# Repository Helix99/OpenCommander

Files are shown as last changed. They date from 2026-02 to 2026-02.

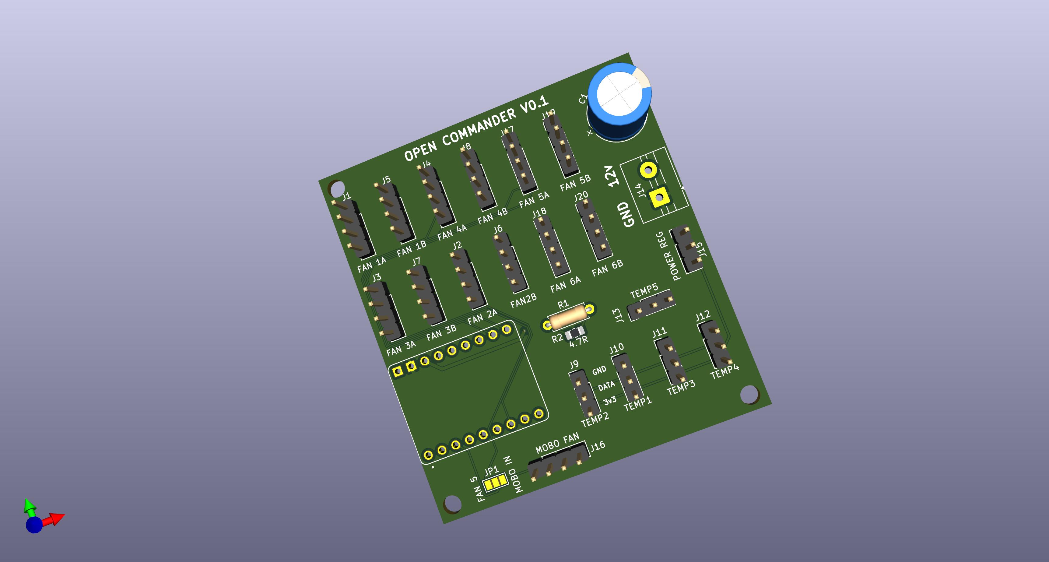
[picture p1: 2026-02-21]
esp32_fan_controller_v0.1.jpg

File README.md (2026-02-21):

# OpenCommander
USB Fan and temprature sensor managment firmware, application and board.

I have a linux server but the supermicro motherboard has limited fan headders and thermal zones. I wanted a much more flexible thermal management solution for it. 

Can manage 6 groups of 2 fans (12 total)
Up to 5 x DS18B20 temprature sensors
Posibillity to disable fan 5 and use pin as input from motherboard fan headder (yet to be implimented in firmware)

Emulates the corsair commander pro firmware so that the fans and tempratures show up in Linux using the in tree corsair module.

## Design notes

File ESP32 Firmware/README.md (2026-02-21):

# ESP32-S3 SuperMini Fan Controller

A complete 4-channel PWM fan controller with 5× DS18B20 temperature monitoring, emulating a **Corsair Commander Pro** over USB HID. Works natively with Linux `lm-sensors`, `fancontrol`, and Prometheus/Grafana — zero custom drivers.

---

## Features

- 6× 4-pin PWM fans (25 kHz, 8-bit, 0–100%)
- 5× DS18B20 temperature sensors (1-Wire, 12-bit, 0.0625 °C resolution)
- Independent fan curves with hysteresis per fan
- Safety override: all fans → 100% if any sensor exceeds 85 °C
- Smooth PWM ramping (prevents bearing stress)
- Friendly sensor names stored in NVS across reboots
- Composite USB: CDC serial + HID simultaneously on one USB-C cable
- Corsair Commander Pro HID protocol (VID `0x1b1c` / PID `0x0c10`)
- Automatic `corsair-cpro` kernel driver load on Linux ≥ 5.8
- JSON serial protocol for Python CLI / scripting

---

## Hardware

### Bill of Materials

| Component | Qty | UK/EU Source | US Source |
|---|---|---|---|
| ESP32-S3 SuperMini | 1 | AliExpress ~£3 | Amazon/AliExpress ~$4 |
| DS18B20 (TO-92) | 5 | Farnell, AliExpress | Mouser, DigiKey |
| 4.7 kΩ resistor | 1 | Any | Any |
| 1 kΩ resistor | 4 | Any | Any |
| 100 nF ceramic cap | 4 | Any | Any |
| 10 µF electrolytic cap | 2 | Any | Any |
| 4-pin PWM fan header (PCB) | 4 | AliExpress | Amazon |
| 12 V PSU (≥5 A for 4× 120 mm fans) | 1 | Amazon ~£12 | Amazon ~$15 |
| Screw terminals / prototype PCB | 1 set | AliExpress | Amazon |

### Pin Assignments

| Function | GPIO | Notes |
|---|---|---|
| PWM Fan 1–4 | 1, 2, 3, 4 | LEDC output, 3.3 V logic OK |
| Tachometer Fan 1–4 | 5, 6, 7, 8 | INPUT_PULLUP, FALLING edge ISR |
| 1-Wire (DS18B20) | 9 | External 4.7 kΩ pull-up to 3.3 V |
| Status LED | 48 | Built-in on SuperMini |
| USB D−/D+ | 19/20 | **Reserved — do not use** |
| Strapping | 0, 45, 46 | **Avoid for peripherals** |

### Wiring Diagram

```
                  ESP32-S3 SuperMini
                 ┌──────────────────┐
            3.3V │                  │ GPIO1 ──PWM──► Fan1 Pin4
             GND │                  │ GPIO2 ──PWM──► Fan2 Pin4
                 │                  │ GPIO3 ──PWM──► Fan3 Pin4
                 │                  │ GPIO4 ──PWM──► Fan4 Pin4
                 │                  │
                 │                  │ GPIO5 ◄─TACH── Fan1 Pin3
                 │                  │ GPIO6 ◄─TACH── Fan2 Pin3
                 │                  │ GPIO7 ◄─TACH── Fan3 Pin3
                 │                  │ GPIO8 ◄─TACH── Fan4 Pin3
                 │                  │
                 │                  │ GPIO9 ◄──┬──► DS18B20 ×5 (DQ)
                 │             3.3V ├──────────┤ 4.7 kΩ pull-up
                 │                  │
                 │  USB-C (19/20)   │◄──────────────── USB to Linux host
                 └──────────────────┘

Fan 4-pin connector:
  Pin1 GND  ──── Common ground
  Pin2 12V  ──── 12 V PSU
  Pin3 TACH ──── 1 kΩ ──── GPIO (internal pull-up active)
  Pin4 PWM  ──── GPIO output

DS18B20 (×5, all in parallel):
  VDD ──── 3.3 V
  GND ──── GND
  DQ  ──┬─ GPIO 9
        └─ 4.7 kΩ ──── 3.3 V

Power rail (CRITICAL — shared ground):
  12 V PSU(+) ──── Fan Pin2 (×4)
  12 V PSU(−) ──┬─ Fan Pin1 (×4)
                └─ ESP32-S3 GND
```

---

## PlatformIO Setup

### Install

```bash
pip install platformio
# Or use VS Code with the PlatformIO extension
```

### Flash (first time — BOOT mode entry)

1. Hold **BOOT** button on the SuperMini
2. Press and release **RESET** while holding BOOT
3. Release **BOOT** — device enters download mode
4. Run:

```bash
cd esp32s3-fan-controller
pio run --target upload
```

After the first flash, subsequent uploads work automatically over CDC serial if ARDUINO_USB_CDC_ON_BOOT is handled correctly, or repeat the BOOT+RESET sequence.

### Monitor

```bash
pio device monitor -b 115200 -p /dev/ttyACM0
```

---

## First-Run Guide

### 1. Flash firmware

Follow the BOOT mode entry steps above.

### 2. Open serial terminal

```bash
screen /dev/ttyACM0 115200
# or: pio device monitor
```

### 3. Discover sensors

```
LIST_SENSORS
{"sensors":[{"index":0,"rom":"28FF3A2B0C000042","name":"Sensor 1"},…]}
```

### 4. Assign friendly names

```
SET_NAME 28FF3A2B0C000042 CPU Temperature
SET_NAME 28FF... GPU Temperature
```

### 5. Verify temperatures

```
GET_TEMPS
{"temps":[{"name":"CPU Temperature","rom":"28FF3A2B0C000042","value":42.5,"valid":true},…]}
```

### 6. Set fan curves

```
SET_CURVE 1 [[20,30],[40,50],[60,75],[80,100]]
SET_CURVE 2 [[20,30],[40,50],[60,75],[80,100]]
```

### 7. Map sensors to fans

```
SET_MAPPING 1 0   # Fan 1 follows sensor 0
SET_MAPPING 2 1   # Fan 2 follows sensor 1
```

### 8. Enable Corsair HID (device will reboot)

```
HID_ENABLE
```

### 9. Verify Linux detection

```bash
sensors
# Should show corsaircpro-hid-* with temperatures and RPMs
```

---

## Serial Protocol Reference

All commands are plain text. All responses are JSON terminated with `\n`.

| Command | Arguments | Response |
|---|---|---|
| `GET_TEMPS` | — | `{"temps":[{"name":"CPU","rom":"28FF…","value":45.5,"valid":true},…]}` |
| `GET_RPMS` | — | `{"rpms":[1200,1350,980,1100]}` |
| `SET_FAN` | `<fan 1–4> <pct 0–100>` | `{"ok":true}` |
| `SET_AUTO` | `<fan 1–4>` | `{"ok":true}` |
| `SET_ALL_AUTO` | — | `{"ok":true}` |
| `GET_CURVE` | `<fan 1–4>` | `{"fan":1,"curve":[[20,30],[40,50],…]}` |
| `SET_CURVE` | `<fan> [[t,p],…]` | `{"ok":true}` |
| `GET_MAPPING` | — | `{"mapping":[0,0,1,1]}` |
| `SET_MAPPING` | `<fan 1–4> <sensor 0–4>` | `{"ok":true}` |
| `LIST_SENSORS` | — | `{"sensors":[{"index":0,"rom":"28FF…","name":"CPU"},…]}` |
| `SET_NAME` | `<rom_hex> <name>` | `{"ok":true}` |
| `GET_STATUS` | — | Full system status JSON |
| `HID_ENABLE` | — | Reboots with HID active |
| `HID_DISABLE` | — | Reboots without HID |
| `SAVE_CONFIG` | — | `{"ok":true}` (no-op, saved on change) |
| `FACTORY_RESET` | — | Clears NVS, reboots |
| `VERSION` | — | `{"fw":"1.0.0","board":"ESP32-S3-SuperMini"}` |

---

## Corsair Commander Pro Protocol

HID reports: 16 bytes IN (device→host) and 16 bytes OUT (host→device).

| Cmd byte | Function | Request | Response |
|---|---|---|---|
| `0x01` | Firmware version | `[0x01, 0x00, …]` | `[0x01, 0x00, 0x09, 0x45]` |
| `0x02` | Product name | `[0x02, …]` | `[0x02, "Commander Pro"…]` |
| `0x08` | Sensor count | `[0x08, …]` | `[0x08, 0x05]` |
| `0x09` | Fan count | `[0x09, …]` | `[0x09, 0x04]` |
| `0x10` | Get temperature | `[0x10, sensor_idx, …]` | `[0x10, hi, lo]` (hundredths °C) |
| `0x21` | Get fan RPM | `[0x21, fan_idx, …]` | `[0x21, hi, lo]` |
| `0x23` | Set fan PWM % | `[0x23, fan_idx, pct, …]` | `[0x23, 0x00]` |
| `0x60` | Set fan mode | `[0x60, fan_idx, mode, …]` | `[0x60, 0x00]` (0=manual, 1=auto) |

---

## Fan Curve Profiles

### Silent
`[[20,20],[35,25],[50,40],[65,60],[75,85],[85,100]]`

### Balanced (default)
`[[20,30],[40,50],[60,75],[80,100]]`

### Performance
`[[20,50],[35,65],[50,80],[60,100]]`

---

## Linux Integration

### Automatic with corsair-cpro kernel module (Linux ≥ 5.8)

```bash
# Plug in with HID enabled — driver loads automatically
cat /sys/class/hwmon/hwmon*/name | grep corsair
# corsaircpro

sensors
# Shows temps and fan RPMs
```

### Sensor labels — /etc/sensors.d/fan-controller.conf

```conf
chip "corsaircpro-*"
    label temp1 "CPU Temperature"
    label temp2 "GPU Temperature"
    label temp3 "Motherboard"
    label temp4 "Intake Air"
    label temp5 "Exhaust Air"
    label fan1  "CPU Fan"
    label fan2  "GPU Fan"
    label fan3  "Front Intake"
    label fan4  "Rear Exhaust"
```

### fancontrol

```bash
sudo pwmconfig   # Auto-generates /etc/fancontrol
sudo systemctl enable --now fancontrol
```

### Prometheus (node_exporter)

```bash
node_exporter --collector.hwmon
# node_hwmon_temp_celsius{chip="corsaircpro",sensor="temp1"} 45.5
# node_hwmon_fan_rpm{chip="corsaircpro",sensor="fan1"} 1200
```

---

## Troubleshooting

### SuperMini not detected / upload fails
- Enter BOOT mode: hold BOOT, press RESET, release BOOT
- Check USB cable supports data (not charge-only)
- Try `lsusb` to confirm device appears

### HID not enumerating
- Verify `USB_VID=0x1b1c`, `USB_PID=0x0c10` build flags are present
- Check `ARDUINO_USB_MODE=0` is set (native USB, not UART bridge)
- Inspect `lsusb -v` output

### corsair-cpro module not loading
```bash
uname -r        # Kernel must be ≥ 5.8
modprobe corsair-cpro
dmesg | tail    # Check for binding errors
```

### DS18B20 not found (GET_TEMPS returns empty)
- Confirm 4.7 kΩ pull-up is on DQ line to 3.3 V
- Confirm sensors are NOT in parasite mode (VDD tied to 3.3 V, not left floating)
- Try with a single sensor first
- Check GPIO 9 is free (no other peripheral assigned)

### Fan tachometer reads 0 RPM
- Confirm `IRAM_ATTR` on ISR functions (already present in source)
- Check 1 kΩ series resistor and internal pull-up on GPIO 5–8
- Verify fan Pin 3 tach wire is connected
- Some fans emit 1 pulse/rev — adjust `TACH_PULSES_PER_REV` in `shared_types.h`

### CDC serial and HID not both present
- Confirm composite USB setup: `hidHandler_init()` called before `USB.begin()`
- Check `ARDUINO_USB_CDC_ON_BOOT=0` — CDC must be managed manually (done in `main.cpp`)
- If only one interface appears, try a powered USB hub (some ports limit current during enumeration)

---

## Code Structure

```
esp32s3-fan-controller/
├── platformio.ini           Board, framework, build flags, lib deps
├── include/
│   └── shared_types.h       All structs, enums, pin/constant defines
└── src/
    ├── main.cpp             Setup, USB init, FreeRTOS task creation, heartbeat
    ├── config_store.cpp/h   Preferences NVS wrapper (curves, mapping, names, HID flag)
    ├── fan_control.cpp/h    LEDC PWM init, duty write, ramping
    ├── tachometer.cpp/h     ISR pulse counting, RPM calculation, stall detection
    ├── temperature.cpp/h    OneWire/DallasTemperature async read, ROM→hex helpers
    ├── fan_curve.cpp/h      Breakpoint interpolation, hysteresis, safety override
    ├── hid_handler.cpp/h    USBHIDGeneric subclass, Commander Pro protocol
    └── serial_handler.cpp/h CDC command parser, JSON responses (ArduinoJson)
```

### FreeRTOS Tasks

| Task | Core | Period | Responsibility |
|---|---|---|---|
| `HID` | 0 | 2000 ms | Push Commander Pro HID report, process host commands |
| `Serial` | 0 | Event | Parse CDC serial commands, return JSON |
| `Temp` | 1 | 2000 ms | Async DS18B20 conversion + read |
| `Control` | 1 | 50 ms | Apply fan curves, ramp PWM |
| `Tacho` | 1 | 2000 ms | Calculate RPM from ISR counters |

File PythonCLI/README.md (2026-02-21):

# ESP32-S3 Fan Controller CLI

Companion Python app for the ESP32-S3 SuperMini fan controller firmware
with Corsair Commander Pro emulation.

---

## Requirements

Python 3.10+ (uses `X | Y` type hints and `match`)

```bash
pip install -r requirements.txt
```

---

## Quick Start

```bash
# Auto-detect the device port
python fan_controller_cli.py

# Specify port explicitly
python fan_controller_cli.py --port /dev/ttyACM0

# Windows
python fan_controller_cli.py --port COM5

# Jump straight to live dashboard
python fan_controller_cli.py --dashboard
```

The last-used port is saved to `~/.fan_controller_config.json` so you won't
need to select it again on subsequent runs.

---

## Features

| Feature | Description |
|---|---|
| **Auto port detection** | Scans for CDC ACM / Corsair VID devices automatically |
| **Live dashboard** | Refreshes every 2 s — all temperatures + fan RPMs with colour coding |
| **Manual fan control** | Set any fan to a fixed PWM % or return to auto/curve mode |
| **Fan curve editor** | Built-in presets (Silent / Balanced / Performance) + custom entry |
| **Sensor naming wizard** | Lists discovered DS18B20 ROM addresses and prompts for friendly names |
| **Sensor mapping** | Choose which temperature sensor controls each fan |
| **HID toggle** | Enable/disable Corsair Commander Pro USB HID emulation (triggers reboot) |
| **Export** | Save current readings to JSON or CSV with timestamp |
| **Device status** | Firmware version, board ID, uptime, HID state |
| **Factory reset** | Double-confirmed wipe of all NVS config |

---

## Live Dashboard

Colour coding:

| Colour | Meaning |
|---|---|
| Green | Normal (temp < 50 °C / fan spinning) |
| Yellow | Warm (temp 50–70 °C) |
| Orange | Hot (temp 70–80 °C) |
| Red | Critical (temp ≥ 80 °C) or fan stalled (0 RPM) |

---

## Fan Curve Presets

| Profile | Breakpoints |
|---|---|
| Silent | 20→20%, 35→25%, 50→40%, 65→60%, 75→85%, 85→100% |
| Balanced | 20→30%, 40→50%, 60→75%, 80→100% |
| Performance | 20→50%, 35→65%, 50→80%, 60→100% |

You can also enter custom breakpoints with up to 8 points. Temperatures must
be strictly ascending.

---

## Linux `sensors` Integration

After enabling HID emulation and rebooting the device:

```bash
# Verify the kernel driver loaded
$ lsmod | grep corsair
corsair_cpro           ...

# Check hwmon
$ sensors
corsaircpro-hid-3-3
Adapter: HID adapter
CPU Temperature:  +45.5°C
GPU Temperature:  +52.2°C
fan1:            1200 RPM
fan2:            1350 RPM
fan3:             980 RPM
fan4:            1100 RPM
```

Add sensor labels in `/etc/sensors.d/fan-controller.conf`:

```conf
chip "corsaircpro-*"
    label temp1 "CPU Temperature"
    label temp2 "GPU Temperature"
    label temp3 "Motherboard"
    label fan1  "CPU Fan"
    label fan2  "GPU Fan"
```

---

## Troubleshooting

**Device not detected**
- Check the ESP32-S3 is powered and the USB-C cable supports data
- Try entering download mode: hold BOOT, press RESET, release BOOT
- On Linux check `dmesg | grep ttyACM` after plugging in
- Add yourself to the `dialout` group: `sudo usermod -aG dialout $USER` (re-login required)

**Timeout errors**
- The firmware may still be booting — wait ~3 s and retry
- Check baud rate matches firmware (default 115200)
- Try unplugging and replugging the USB cable

**HID not loading `corsair-cpro`**
- Requires kernel 5.8+: `uname -r`
- Try: `sudo modprobe corsair-cpro`
- Verify VID/PID: `lsusb | grep -i corsair` should show `1b1c:0c10`

**Fan RPM reading 0**
- Check tachometer wiring (Fan Pin 3) and pull-up
- ISR functions must be marked `IRAM_ATTR` in firmware
- Some fans don't emit tach pulses below ~20% PWM — raise minimum speed

**DS18B20 shows -127 °C**
- Sensor disconnected or wiring fault
- Check 4.7 kΩ pull-up resistor on the data line
- Ensure NOT using parasite mode (VDD connected to 3.3 V, not data line)

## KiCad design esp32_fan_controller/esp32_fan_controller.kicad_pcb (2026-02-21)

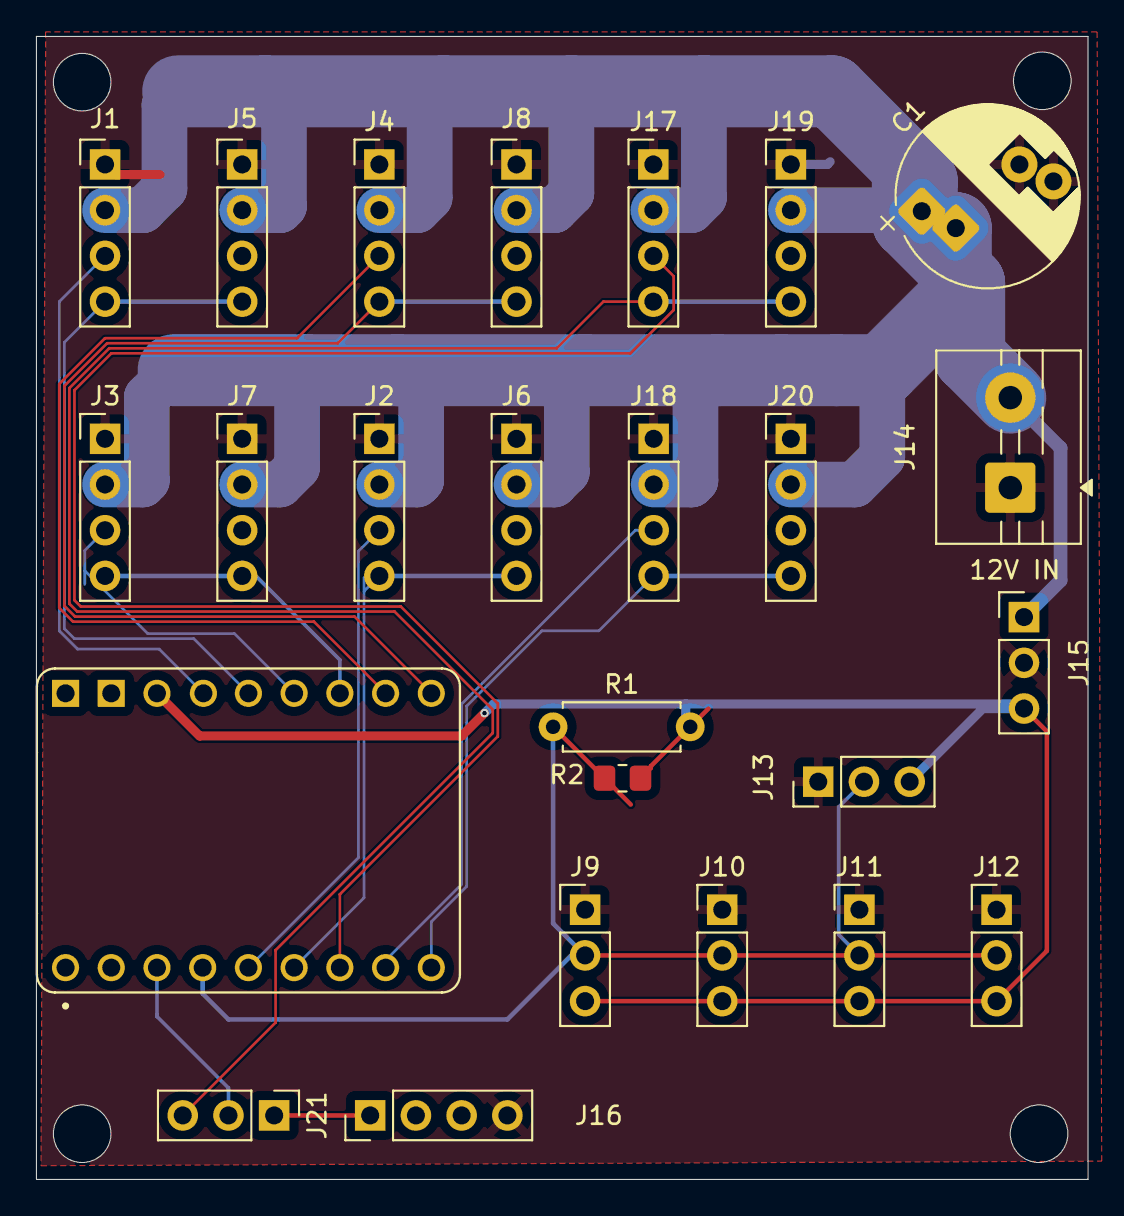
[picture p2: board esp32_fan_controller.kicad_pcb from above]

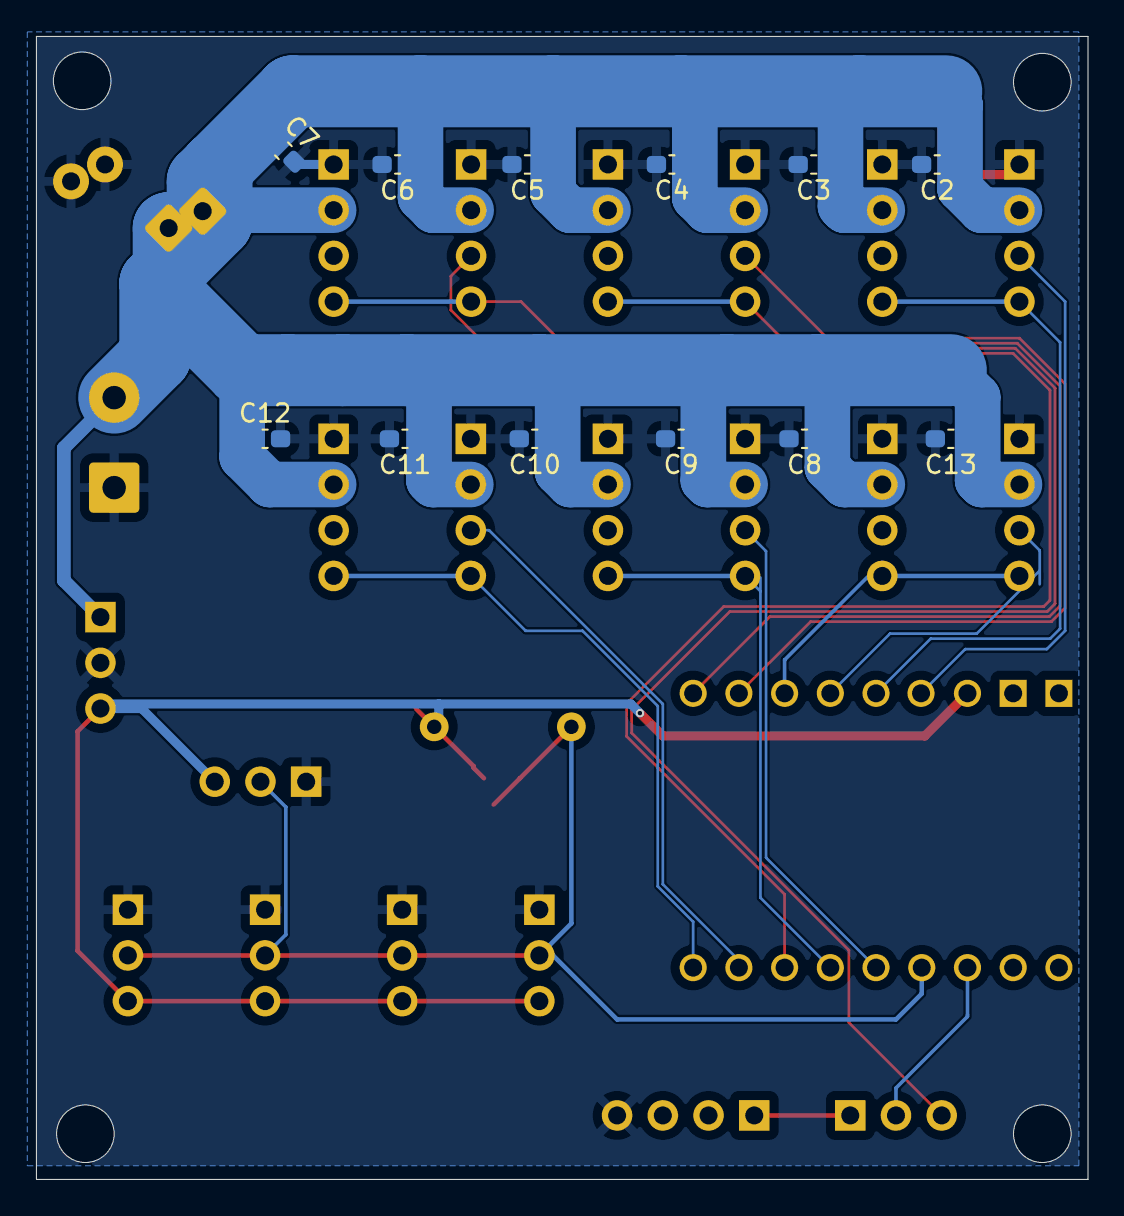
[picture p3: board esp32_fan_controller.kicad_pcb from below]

Board: 2 copper layers, 58.4 x 63.5 mm, 37 parts (12 on the bottom side), 18 nets.

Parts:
C1: C_Polarized; CP_Radial_D10.0mm_P5.00mm_P7.50mm
C2, C3, C4, C5, C6, C7, C8, C9, C10, C11, C12, C13: C; C_0603_1608Metric_Pad1.08x0.95mm_HandSolder
J1: FAN 1A; PinHeader_1x04_P2.54mm_Vertical
J2: FAN 2A; PinHeader_1x04_P2.54mm_Vertical
J3: FAN 3A; PinHeader_1x04_P2.54mm_Vertical
J4: FAN 4A; PinHeader_1x04_P2.54mm_Vertical
J5: FAN 1B; PinHeader_1x04_P2.54mm_Vertical
J6: FAN2B; PinHeader_1x04_P2.54mm_Vertical
J7: FAN 3B; PinHeader_1x04_P2.54mm_Vertical
J8: FAN 4B; PinHeader_1x04_P2.54mm_Vertical
J9: TEMP2; PinHeader_1x03_P2.54mm_Vertical
J10: TEMP1; PinHeader_1x03_P2.54mm_Vertical
J11: TEMP3; PinHeader_1x03_P2.54mm_Vertical
J12: TEMP4; PinHeader_1x03_P2.54mm_Vertical
J13: TEMP5; PinHeader_1x03_P2.54mm_Vertical
J14: 12V IN; TerminalBlock_MaiXu_MX126-5.0-02P_1x02_P5.00mm
J15: POWER REG; PinHeader_1x03_P2.54mm_Vertical
J16: MOBO FAN; PinHeader_1x04_P2.54mm_Vertical
J17: FAN 5A; PinHeader_1x04_P2.54mm_Vertical
J18: FAN 6A; PinHeader_1x04_P2.54mm_Vertical
J19: FAN 5B; PinHeader_1x04_P2.54mm_Vertical
J20: FAN 6B; PinHeader_1x04_P2.54mm_Vertical
J21: GPIO1; PinHeader_1x03_P2.54mm_Vertical
R1: R; R_Axial_DIN0207_L6.3mm_D2.5mm_P7.62mm_Horizontal
R2: 4.7R; R_0805_2012Metric_Pad1.20x1.40mm_HandSolder
U1: ESP32-S3 SuperMini; ESP32-S3-SuperMini

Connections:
+3.3V: J9.3, J10.3, J11.3, J12.3, J13.3, J15.3, R1.2, R2.2
+12V: C1.1, C2.1, C3.1, C4.1, C5.1, C6.1, C7.1, C8.1, C9.1, C10.1, C11.1, C12.1, C13.1, J1.2, J2.2, J3.2, J4.2, J5.2, J6.2, J7.2, J8.2, J14.2, J15.1, J17.2, J18.2, J19.2, J20.2
GND: C1.2, C2.2, C3.2, C4.2, C5.2, C6.2, C7.2, C8.2, C9.2, C10.2, C11.2, C12.2, C13.2, J1.1, J2.1, J3.1, J4.1, J5.1, J6.1, J7.1, J8.1, J9.1, J10.1, J11.1, J12.1, J13.1, J14.1, J15.2, J16.4, J17.1, J18.1, J19.1, J20.1
unnamed: J1.3, U1.13 (GPIO13)
unnamed: J1.4, J5.4, U1.12 (GPIO12)
unnamed: J2.3, U1.3 (GPIO3)
unnamed: J2.4, J6.4, U1.4 (GPIO4)
unnamed: J3.3, U1.11 (GPIO11)
unnamed: J3.4, J7.4, U1.10 (GPIO10)
unnamed: J4.3, U1.9 (GPIO9)
unnamed: J4.4, J8.4, U1.8 (GPIO8)
unnamed: J9.2, J10.2, J11.2, J12.2, J13.2, R1.1, R2.1, U1.2 (GPI02)
unnamed: J16.1, J21.1
unnamed: J17.3, U1.5 (GPIO5)
unnamed: J17.4, J19.4, J21.3
unnamed: J18.3, U1.6 (GPIO6)
unnamed: J18.4, J20.4, U1.7 (GPIO7)
unnamed: J21.2, U1.1 (GPIO1)

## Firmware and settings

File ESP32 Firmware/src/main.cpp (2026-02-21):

/*
 * ESP32-S3 SuperMini Fan Controller
 * Corsair Commander Pro Emulation + CDC Serial Control
 *
 * Core 0: USB HID task, Serial handler task
 * Core 1: Temperature task, Fan control task, Tachometer task
 *
 * All shared state in g_state, protected by g_stateMutex.
 */

#include <Arduino.h>
#include <USB.h>
#include <USBCDC.h>
#include <freertos/FreeRTOS.h>
#include <freertos/task.h>
#include <freertos/semphr.h>

#include "shared_types.h"
#include "config_store.h"
#include "fan_control.h"
#include "tachometer.h"
#include "temperature.h"
#include "fan_curve.h"
#include "hid_handler.h"
#include "serial_handler.h"

// ─── Global State ────────────────────────────────────────────────────────────

SystemState         g_state;
SemaphoreHandle_t   g_stateMutex;
USBCDC              USBSerial;

// ─── Task Handles ────────────────────────────────────────────────────────────

TaskHandle_t taskHID     = nullptr;
TaskHandle_t taskSerial  = nullptr;
TaskHandle_t taskTemp    = nullptr;
TaskHandle_t taskControl = nullptr;
TaskHandle_t taskTacho   = nullptr;

// ─────────────────────────────────────────────────────────────────────────────
// Core 0 Tasks — USB Protocol
// ─────────────────────────────────────────────────────────────────────────────

// HID Task: push Commander Pro status report every 2s,
// and process any incoming HID commands from the host.
void taskHID_fn(void* /*pvParam*/) {
    const TickType_t period = pdMS_TO_TICKS(2000);
    TickType_t lastWake = xTaskGetTickCount();

    for (;;) {
        if (xSemaphoreTake(g_stateMutex, pdMS_TO_TICKS(50))) {
            hidHandler_processIncoming(g_state);
            hidHandler_pushStatusReport(g_state);
            xSemaphoreGive(g_stateMutex);
        }
        vTaskDelayUntil(&lastWake, period);
    }
}

// Serial Task: process CDC serial commands (event-driven).
void taskSerial_fn(void* /*pvParam*/) {
    for (;;) {
        if (USBSerial && USBSerial.available()) {
            if (xSemaphoreTake(g_stateMutex, pdMS_TO_TICKS(100))) {
                serialHandler_tick(g_state);
                xSemaphoreGive(g_stateMutex);
            }
        }
        vTaskDelay(pdMS_TO_TICKS(10)); // Yield; avoid busy-loop
    }
}

// ─────────────────────────────────────────────────────────────────────────────
// Core 1 Tasks — Sensors & Control
// ─────────────────────────────────────────────────────────────────────────────

// Temperature Task: async DS18B20 conversion + read every 2s.
void taskTemp_fn(void* /*pvParam*/) {
    for (;;) {
        // Start conversion — non-blocking command
        temperature_startConversion();

        // Wait for 12-bit conversion to complete (~800ms to be safe)
        vTaskDelay(pdMS_TO_TICKS(800));

        // Read all sensors into local copies, then update shared state
        SensorState localSensors[NUM_TEMP_SENSORS];
        uint8_t numFound;

        if (xSemaphoreTake(g_stateMutex, pdMS_TO_TICKS(100))) {
            numFound = g_state.numSensorsFound;
            memcpy(localSensors, g_state.sensors, sizeof(localSensors));
            xSemaphoreGive(g_stateMutex);
        }

        temperature_readAll(localSensors, numFound);

        if (xSemaphoreTake(g_stateMutex, pdMS_TO_TICKS(100))) {
            memcpy(g_state.sensors, localSensors, sizeof(localSensors));
            xSemaphoreGive(g_stateMutex);
        }

        // Wait out the rest of the 2s interval
        vTaskDelay(pdMS_TO_TICKS(TEMP_READ_INTERVAL_MS - 800));
    }
}

// Fan Control Task: apply curves and ramp PWM every 100ms (50ms ramp tick × 2).
void taskControl_fn(void* /*pvParam*/) {
    const TickType_t period = pdMS_TO_TICKS(50);
    TickType_t lastWake = xTaskGetTickCount();

    for (;;) {
        if (xSemaphoreTake(g_stateMutex, pdMS_TO_TICKS(30))) {
            // Apply fan curves (auto-mode only)
            fanCurve_applyAll(g_state.fans, g_state.sensors, g_state.numSensorsFound);

            // Ramp each fan one step toward its target
            fanControl_rampTick(g_state.fans);

            xSemaphoreGive(g_stateMutex);
        }
        vTaskDelayUntil(&lastWake, period);
    }
}

// Tachometer Task: calculate RPM every 2s from ISR pulse counts.
void taskTacho_fn(void* /*pvParam*/) {
    const TickType_t period = pdMS_TO_TICKS(TACH_CALC_INTERVAL_MS);
    TickType_t lastWake = xTaskGetTickCount();

    for (;;) {
        FanState localFans[NUM_FANS];

        if (xSemaphoreTake(g_stateMutex, pdMS_TO_TICKS(50))) {
            memcpy(localFans, g_state.fans, sizeof(localFans));
            xSemaphoreGive(g_stateMutex);
        }

        tachometer_update(localFans);

        if (xSemaphoreTake(g_stateMutex, pdMS_TO_TICKS(50))) {
            for (uint8_t i = 0; i < NUM_FANS; i++) {
                g_state.fans[i].rpm     = localFans[i].rpm;
                g_state.fans[i].stalled = localFans[i].stalled;
            }
            xSemaphoreGive(g_stateMutex);
        }

        vTaskDelayUntil(&lastWake, period);
    }
}

// ─────────────────────────────────────────────────────────────────────────────
// Setup
// ─────────────────────────────────────────────────────────────────────────────

void setup() {
    // Status LED
    pinMode(PIN_LED, OUTPUT);
    digitalWrite(PIN_LED, LOW);

    // ── NVS / Preferences ────────────────────────────────────────────────────
    configStore_init();

    // ── Initialise shared state ───────────────────────────────────────────────
    g_stateMutex = xSemaphoreCreateMutex();
    memset(&g_state, 0, sizeof(g_state));
    g_state.bootTime = millis();

    // Load HID preference
    g_state.hidEnabled = configStore_loadHidEnabled();

    // Load per-fan configuration (curves, sensor mapping, start in auto mode)
    for (uint8_t i = 0; i < NUM_FANS; i++) {
        configStore_loadCurve(i, g_state.fans[i].curve);
        g_state.fans[i].sensorIndex   = configStore_loadMapping(i);
        g_state.fans[i].mode          = FAN_MODE_AUTO;
        g_state.fans[i].targetPercent = PWM_MIN_PERCENT;
        g_state.fans[i].currentPercent= PWM_MIN_PERCENT;
    }

    // ── Hardware peripherals ──────────────────────────────────────────────────
    fanControl_init();
    tachometer_init();

    // Discover DS18B20 sensors and populate state
    g_state.numSensorsFound = temperature_init(g_state.sensors);

    // ── USB ───────────────────────────────────────────────────────────────────
    // Order matters for TinyUSB composite device:
    //   1. Set VID/PID/strings before any interface registers
    //   2. hidHandler_init: registers HID interface + spawns high-priority
    //      response task that wakes immediately on OUT report from kernel
    //   3. USBSerial.begin: registers CDC interface
    //   4. USB.begin: starts TinyUSB with all registered interfaces
    USB.VID(0x1b1c);
    USB.PID(0x0c10);
    USB.manufacturerName("OPENCOMMANDER");
    USB.productName("OPENCOMMANDER V0.1");

    hidHandler_init(g_state.hidEnabled);       // registers HID + starts response task
    hidHandler_setStatePtr(&g_state);          // give response task access to live state

    USBSerial.begin(115200);              // registers CDC before stack starts

    USB.begin();                          // starts TinyUSB with all interfaces

    serialHandler_init();

    // Brief wait for USB enumeration
    delay(1000);

    // ── FreeRTOS Tasks ────────────────────────────────────────────────────────
    // Core 0: USB protocol tasks
    xTaskCreatePinnedToCore(taskHID_fn,    "HID",     4096, nullptr, 1, &taskHID,     0);
    xTaskCreatePinnedToCore(taskSerial_fn, "Serial",  4096, nullptr, 2, &taskSerial,  0);

    // Core 1: Sensor & control tasks
    xTaskCreatePinnedToCore(taskTemp_fn,    "Temp",    4096, nullptr, 2, &taskTemp,    1);
    xTaskCreatePinnedToCore(taskControl_fn, "Control", 3072, nullptr, 3, &taskControl, 1);
    xTaskCreatePinnedToCore(taskTacho_fn,   "Tacho",   3072, nullptr, 1, &taskTacho,   1);

    // Blink LED to indicate successful boot
    for (int i = 0; i < 3; i++) {
        digitalWrite(PIN_LED, HIGH); delay(150);
        digitalWrite(PIN_LED, LOW);  delay(150);
    }
}

// ─────────────────────────────────────────────────────────────────────────────
// Loop — runs on Core 1 at idle priority, used only for LED heartbeat.
// All real work is done in the FreeRTOS tasks above.
// ─────────────────────────────────────────────────────────────────────────────
void loop() {
    // Slow heartbeat: ON for 100ms, OFF for 1900ms
    digitalWrite(PIN_LED, HIGH); delay(100);
    digitalWrite(PIN_LED, LOW);  delay(1900);
}

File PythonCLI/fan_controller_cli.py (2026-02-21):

#!/usr/bin/env python3
"""
ESP32-S3 SuperMini Fan Controller CLI
Companion app for the Corsair Commander Pro emulation firmware.

Usage:
    python fan_controller_cli.py [--port /dev/ttyACM0] [--baud 115200]

Requirements:
    pip install pyserial colorama rich
"""

import argparse
import json
import os
import sys
import time
import serial
import serial.tools.list_ports
from datetime import datetime
from pathlib import Path

try:
    from colorama import init as colorama_init, Fore, Style
    colorama_init(autoreset=True)
except ImportError:
    print("ERROR: colorama not installed. Run: pip install colorama")
    sys.exit(1)

try:
    from rich.console import Console
    from rich.table import Table
    from rich.live import Live
    from rich.panel import Panel
    from rich.columns import Columns
    from rich.text import Text
    from rich import box
except ImportError:
    print("ERROR: rich not installed. Run: pip install rich")
    sys.exit(1)

# ─────────────────────────────────────────────────────────────────────────────
# Constants
# ─────────────────────────────────────────────────────────────────────────────

CONFIG_FILE = Path.home() / ".fan_controller_config.json"
CORSAIR_VID = 0x1B1C
CORSAIR_PID = 0x0C10
DEFAULT_BAUD = 115200
SERIAL_TIMEOUT = 3.0
DASHBOARD_REFRESH = 2.0

console = Console()


# ─────────────────────────────────────────────────────────────────────────────
# Config persistence
# ─────────────────────────────────────────────────────────────────────────────

def load_config() -> dict:
    if CONFIG_FILE.exists():
        try:
            with open(CONFIG_FILE) as f:
                return json.load(f)
        except Exception:
            pass
    return {}


def save_config(cfg: dict):
    try:
        with open(CONFIG_FILE, "w") as f:
            json.dump(cfg, f, indent=2)
    except Exception as e:
        console.print(f"[yellow]Warning: could not save config: {e}[/yellow]")


# ─────────────────────────────────────────────────────────────────────────────
# Serial connection helpers
# ─────────────────────────────────────────────────────────────────────────────

def list_candidate_ports() -> list[str]:
    """Return ports likely to be the ESP32-S3 CDC ACM device."""
    candidates = []
    for port in serial.tools.list_ports.comports():
        desc = (port.description or "").lower()
        mfg  = (port.manufacturer or "").lower()
        vid  = port.vid
        # Prefer Corsair VID or obvious CDC/ACM devices
        if vid == CORSAIR_VID:
            candidates.insert(0, port.device)
        elif "acm" in desc or "cdc" in desc or "esp32" in desc or "usb serial" in mfg:
            candidates.append(port.device)
    return candidates


def auto_detect_port() -> str | None:
    cfg = load_config()
    last = cfg.get("last_port")

    candidates = list_candidate_ports()
    if not candidates:
        # Fall back to all serial ports
        candidates = [p.device for p in serial.tools.list_ports.comports()]

    if not candidates:
        return None

    # If last used port is still available, prefer it
    if last and last in candidates:
        candidates.insert(0, last)
        candidates = list(dict.fromkeys(candidates))  # deduplicate, keep order

    if len(candidates) == 1:
        return candidates[0]

    console.print("\n[bold]Available serial ports:[/bold]")
    for i, p in enumerate(candidates):
        marker = " [green]← last used[/green]" if p == last else ""
        console.print(f"  {i+1}. {p}{marker}")

    while True:
        try:
            choice = input(f"\nSelect port [1-{len(candidates)}] (Enter for {candidates[0]}): ").strip()
            if choice == "":
                return candidates[0]
            idx = int(choice) - 1
            if 0 <= idx < len(candidates):
                return candidates[idx]
        except (ValueError, KeyboardInterrupt):
            return candidates[0]


def open_serial(port: str, baud: int = DEFAULT_BAUD) -> serial.Serial:
    ser = serial.Serial(port, baud, timeout=SERIAL_TIMEOUT)
    time.sleep(0.5)  # Let CDC enumerate
    ser.reset_input_buffer()
    return ser


# ─────────────────────────────────────────────────────────────────────────────
# Protocol layer
# ─────────────────────────────────────────────────────────────────────────────

class FanControllerError(Exception):
    pass


class FanController:
    def __init__(self, ser: serial.Serial):
        self.ser = ser

    def _send(self, command: str) -> dict:
        """Send a command and return parsed JSON response.

        The firmware protocol is strictly line-oriented:
          - One command sent as a single line (terminated with newline)
          - One response returned as a single JSON line via USBSerial.println()
          - No echo, no preamble, no multi-line output

        pyserial readline() blocks until a newline arrives or ser.timeout
        expires, which matches the firmware exactly. Non-JSON lines (stray
        debug output) are skipped; we keep reading until we get parseable
        JSON or the overall deadline passes.
        """
        self.ser.reset_input_buffer()
        self.ser.write((command.strip() + "\n").encode())
        self.ser.flush()

        deadline = time.time() + SERIAL_TIMEOUT
        while time.time() < deadline:
            raw = self.ser.readline()       # blocks up to ser.timeout for \n
            if not raw:
                # readline returned empty bytes — no newline within timeout
                raise FanControllerError(
                    f"Timeout waiting for response to: {command!r}"
                )
            line = raw.decode(errors="replace").strip()
            if not line:
                continue                    # skip blank lines
            try:
                return json.loads(line)
            except json.JSONDecodeError:
                # Not JSON — stray debug print; keep reading
                continue

        raise FanControllerError(f"Timeout waiting for response to: {command!r}")

    def get_temps(self) -> list[dict]:
        r = self._send("GET_TEMPS")
        return r.get("temps", [])

    def get_rpms(self) -> list[int]:
        r = self._send("GET_RPMS")
        return r.get("rpms", [0, 0, 0, 0, 0, 0])

    def set_fan(self, fan: int, percent: int) -> bool:
        r = self._send(f"SET_FAN {fan} {percent}")
        return r.get("ok", False)

    def set_auto(self, fan: int) -> bool:
        r = self._send(f"SET_AUTO {fan}")
        return r.get("ok", False)

    def set_all_auto(self) -> bool:
        r = self._send("SET_ALL_AUTO")
        return r.get("ok", False)

    def get_curve(self, fan: int) -> dict:
        return self._send(f"GET_CURVE {fan}")

    def set_curve(self, fan: int, curve: list[list[int]]) -> bool:
        curve_json = json.dumps(curve)
        r = self._send(f"SET_CURVE {fan} {curve_json}")
        return r.get("ok", False)
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

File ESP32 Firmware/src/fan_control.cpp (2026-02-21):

#include "fan_control.h"

static const uint8_t FAN_PINS[NUM_FANS] = {
    PIN_PWM_FAN1, PIN_PWM_FAN2, PIN_PWM_FAN3,
    PIN_PWM_FAN4, PIN_PWM_FAN5, PIN_PWM_FAN6
};

void fanControl_init() {
    for (uint8_t i = 0; i < NUM_FANS; i++) {
        // arduino-esp32 v3.x: ledcAttach(pin, freq, resolution)
        ledcAttach(FAN_PINS[i], PWM_FREQ_HZ, PWM_RESOLUTION_BITS);
        ledcWrite(FAN_PINS[i], fanControl_percentToRaw(PWM_MIN_PERCENT));
    }
}

uint8_t fanControl_percentToRaw(uint8_t percent) {
    // Enforce floor when duty > 0
    if (percent == 0) return 0;
    if (percent < PWM_MIN_PERCENT) percent = PWM_MIN_PERCENT;
    if (percent > 100) percent = 100;
    return (uint8_t)((percent * 255UL) / 100UL);
}

void fanControl_writeRaw(uint8_t fanIndex, uint8_t raw) {
    if (fanIndex >= NUM_FANS) return;
    ledcWrite(FAN_PINS[fanIndex], raw);
}

void fanControl_setTarget(uint8_t fanIndex, uint8_t percent) {
    // Caller is responsible for updating FanState.targetPercent.
    // This just writes PWM directly for immediate manual overrides
    // called outside the ramp loop (e.g. safety override).
    if (fanIndex >= NUM_FANS) return;
    if (percent > 100) percent = 100;
    fanControl_writeRaw(fanIndex, fanControl_percentToRaw(percent));
}

void fanControl_rampTick(FanState fans[NUM_FANS]) {
    for (uint8_t i = 0; i < NUM_FANS; i++) {
        uint8_t target  = fans[i].targetPercent;
        uint8_t current = fans[i].currentPercent;

        if (current < target) {
            uint8_t next = current + PWM_RAMP_STEP;
            fans[i].currentPercent = (next > target) ? target : next;
        } else if (current > target) {
            uint8_t next = (current > PWM_RAMP_STEP) ? current - PWM_RAMP_STEP : 0;
            fans[i].currentPercent = (next < target) ? target : next;
        }

        fanControl_writeRaw(i, fanControl_percentToRaw(fans[i].currentPercent));
    }
}

void fanControl_safetyOverride() {
    for (uint8_t i = 0; i < NUM_FANS; i++) {
        fanControl_writeRaw(i, 255);
    }
}

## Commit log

2026-02-21 Update README to reflect 6 PWM fans support
2026-02-21 Update README with project details and capabilities
    Expanded project description and clarified fan and sensor management capabilities.
